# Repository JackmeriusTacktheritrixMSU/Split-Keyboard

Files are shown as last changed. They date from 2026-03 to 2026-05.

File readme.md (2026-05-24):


	This is a split keyboard loosely based on Hack Club's (https://stasis.hackclub.com/starter-projects/split-keyboard.)
It runs from bluetooth, on two NRF52840 Pro Micro clone boards that you can get on aliexpress for cheap. 

Why'd I make it?
Its a bit of a deviation from the standard split keyboard dealy. Generally people use these same switches, but they

A. Expose the MCU on the top face of the keyboard halves
B. Use very few keys (Like a 45 percent keyboard or something along those lines)
and 
C. Use super flat, spread out keycaps.
I'm not crazy about any of these. I like traditional keyboards okay, and I have no idea how people remember which key is which on their splits. I wanted mine to be more standard- with the split for ergnomics but fairly status quo
everywhere else. I like the feeling of regular keycaps-- I like the look as well. I wanted to design my own keycaps. I got the little plug insert bits just from user fivedee on printables \
(https://www.printables.com/model/1069263-15x15-minimal-spaced-kailh-choc-keycap/files)  
Everything else I cut out and built my own. The result is some monster sized caps- turning low profile switches into a very much not low profile keyboard- which is what I wanted, but I might need to change things in the future and 
make my caps lighter. As of now they are untested. 
Capture

The design is screws coming up from the bottom. The two sides mesh together with a nice offset surface.
FinalReal
The PCB is actually reversed for the final- because it has kailh hot swap switches on it


BOM
| Item | Count | Price Per Unit | Total Price | Link | Status |
|---|---:|---:|---:|---|---|
| M2 Heatset Inserts (3.2 x 3.2mm) | 21 | N/A | N/A | N/A | Have |
| NRF52840 Dev Board | Pack x2 | N/A | $0.99 | [Link](https://www.aliexpress.us/item/3256807018711621.html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) | Need |
| PCB | Pack x5 (dev min) | N/A | $25.70 | N/A? | Need |
| Li-ion Poly Battery 5000mAh | Pack x2 | N/A | $14.13 | [Link](https://www.aliexpress.us/item/3256809787664995.html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) | Need |
| Choc V1 Switches | 77 | N/A | N/A | [Link](https://www.aliexpress.us/item/3256809185516557.html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) | Have |
| PG1350 Sockets | 77 | N/A | N/A | [Link](https://www.aliexpress.us/item/3256805079542148.html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) | Have |
| 1N4184W Diodes | 100 | N/A | $4.77 | [Link](https://www.aliexpress.us/item/3256809772352005.html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) | Need |
| 0805 820k Ohm SMD resistor | 100 | N/A | N/A | N/A | Have? |
| 0805 2M Ohm SMD resistor | 100 | N/A | N/A | N/A | Have? |
| M2 Screws (20mm x8 and 4mm x8)| 16 | N/A | N/A | N/A | Have? |
| 3DPrinted Shells+Plate| 3 | N/A | N/A | N/A | Have? |
| Shipping |  |  | $20.73 |  |  |
| Coupons |  |  | -$13.00 |  |  |
| **Total** |  |  | **$53.32** |  |  |

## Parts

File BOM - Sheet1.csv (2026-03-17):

Item | Count | Price Per Unit | Total Price | Link | Status
M2 Heatset Inserts (3.2 x 3.2mm | 21 | N/A | N/A | N/A | Have
NRF52840 Dev Board | Pack x2 | N/A | $0.99 | https://www.aliexpress.us/item/3256807018711621.html?mp=1 | Need
PCB | Pack x5 (dev min) | N/A | $25.70 | N/A? | Need
Li-ion Poly Battery 5000mAh | Pack x2 | N/A | $14.13 | https://www.aliexpress.us/item/3256809787664995.html?mp=1 | Need
Choc V1 Switches | 77 | N/A | N/A | https://www.aliexpress.us/item/3256809185516557.html?src=google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 | Have
PG1350 Sockets | 77 | N/A | N/A | https://www.aliexpress.us/item/3256805079542148.html?src=google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 | Have
1N4184W Diodes | 100 | N/A | $4.77 | https://www.aliexpress.us/item/3256809772352005.html?mp=1 | Need
0805 820k Ohm SMD resistor | 100 | N/A | N/A | N/A | Have?
0805 2M Ohm SMD resistor | 100 | N/A | N/A | N/A | Have?
Shipping |  |  | $20.73
Coupons |  |  | -$13
Total |  |  | $53.32

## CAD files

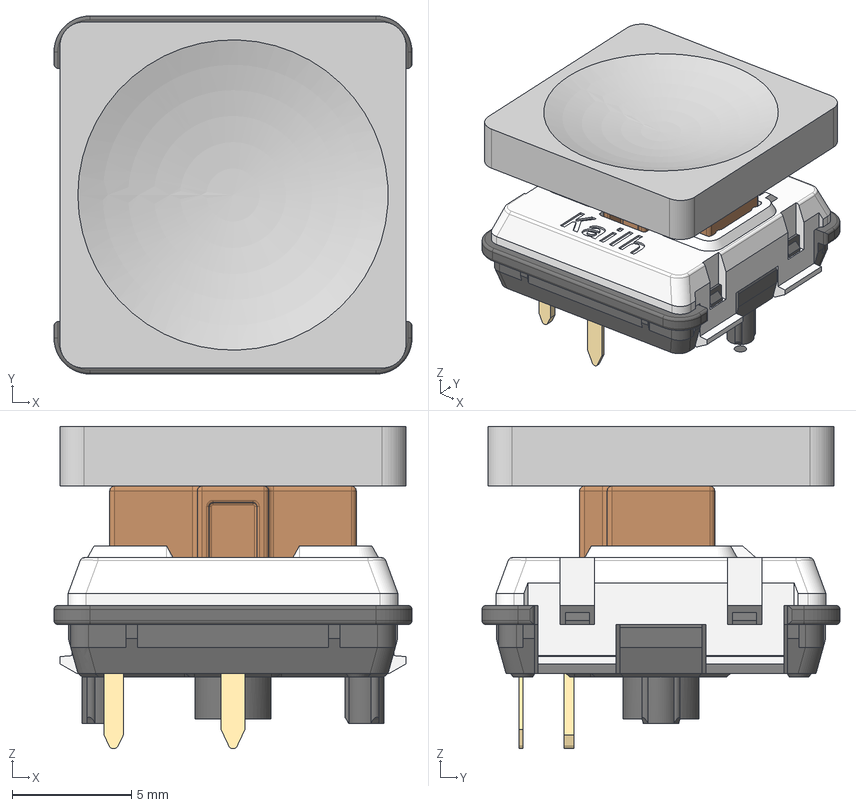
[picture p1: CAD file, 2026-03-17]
CAD Assembly/minspaced-choc-keycap.step
15.0 x 15.0 x 13.5 mm

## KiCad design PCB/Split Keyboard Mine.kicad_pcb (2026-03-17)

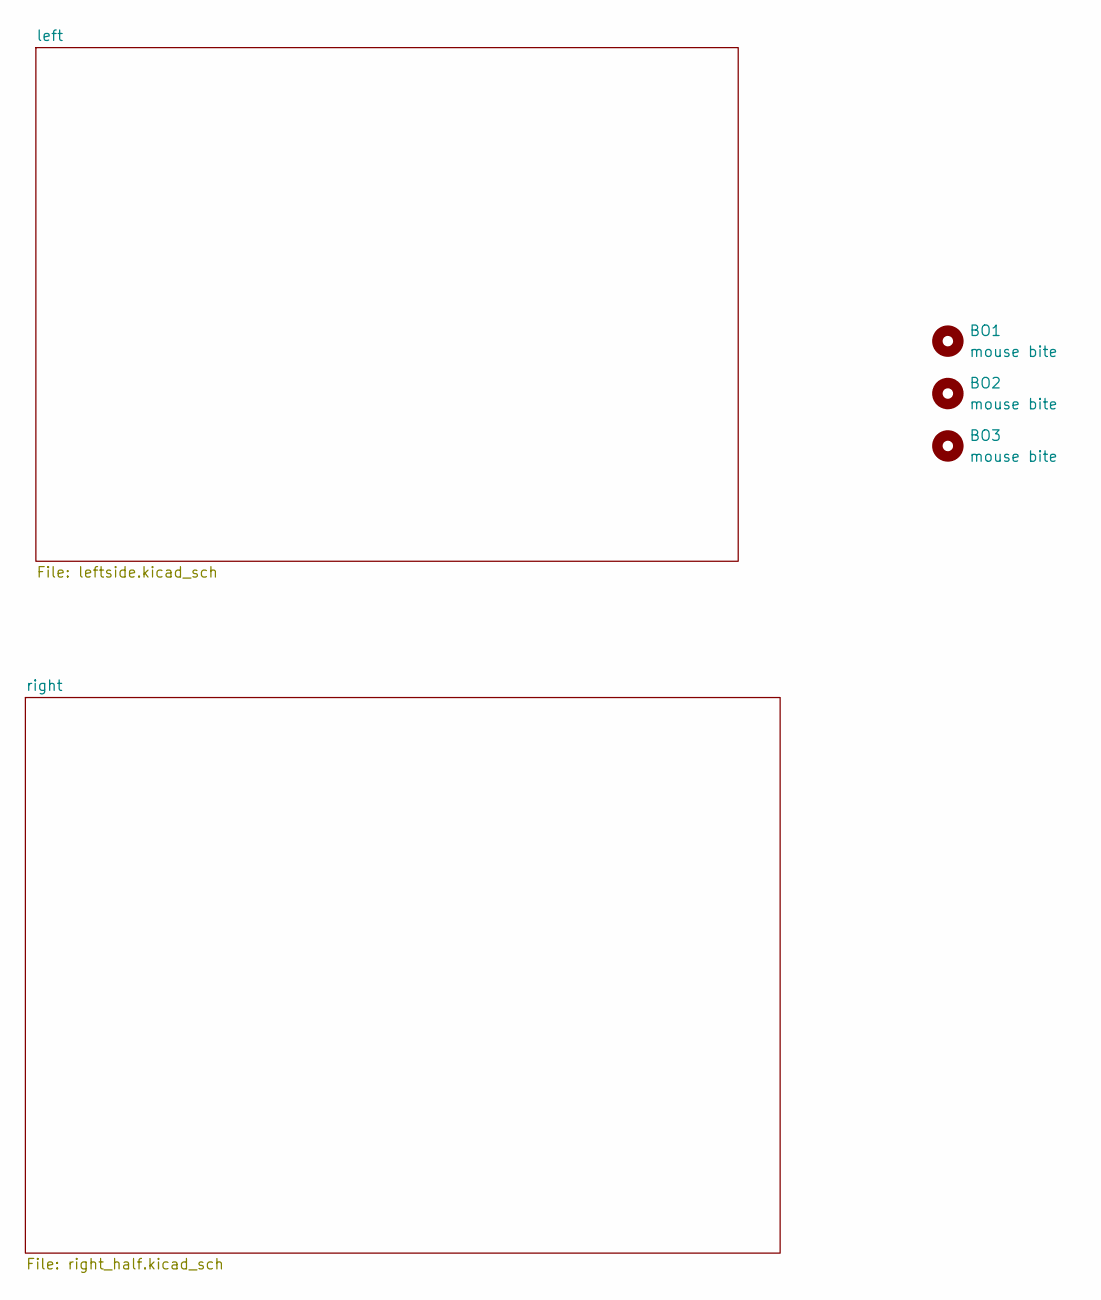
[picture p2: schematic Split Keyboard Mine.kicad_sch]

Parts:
BO1, BO2, BO3: mouse bite; mouse-bite-5mm-slot

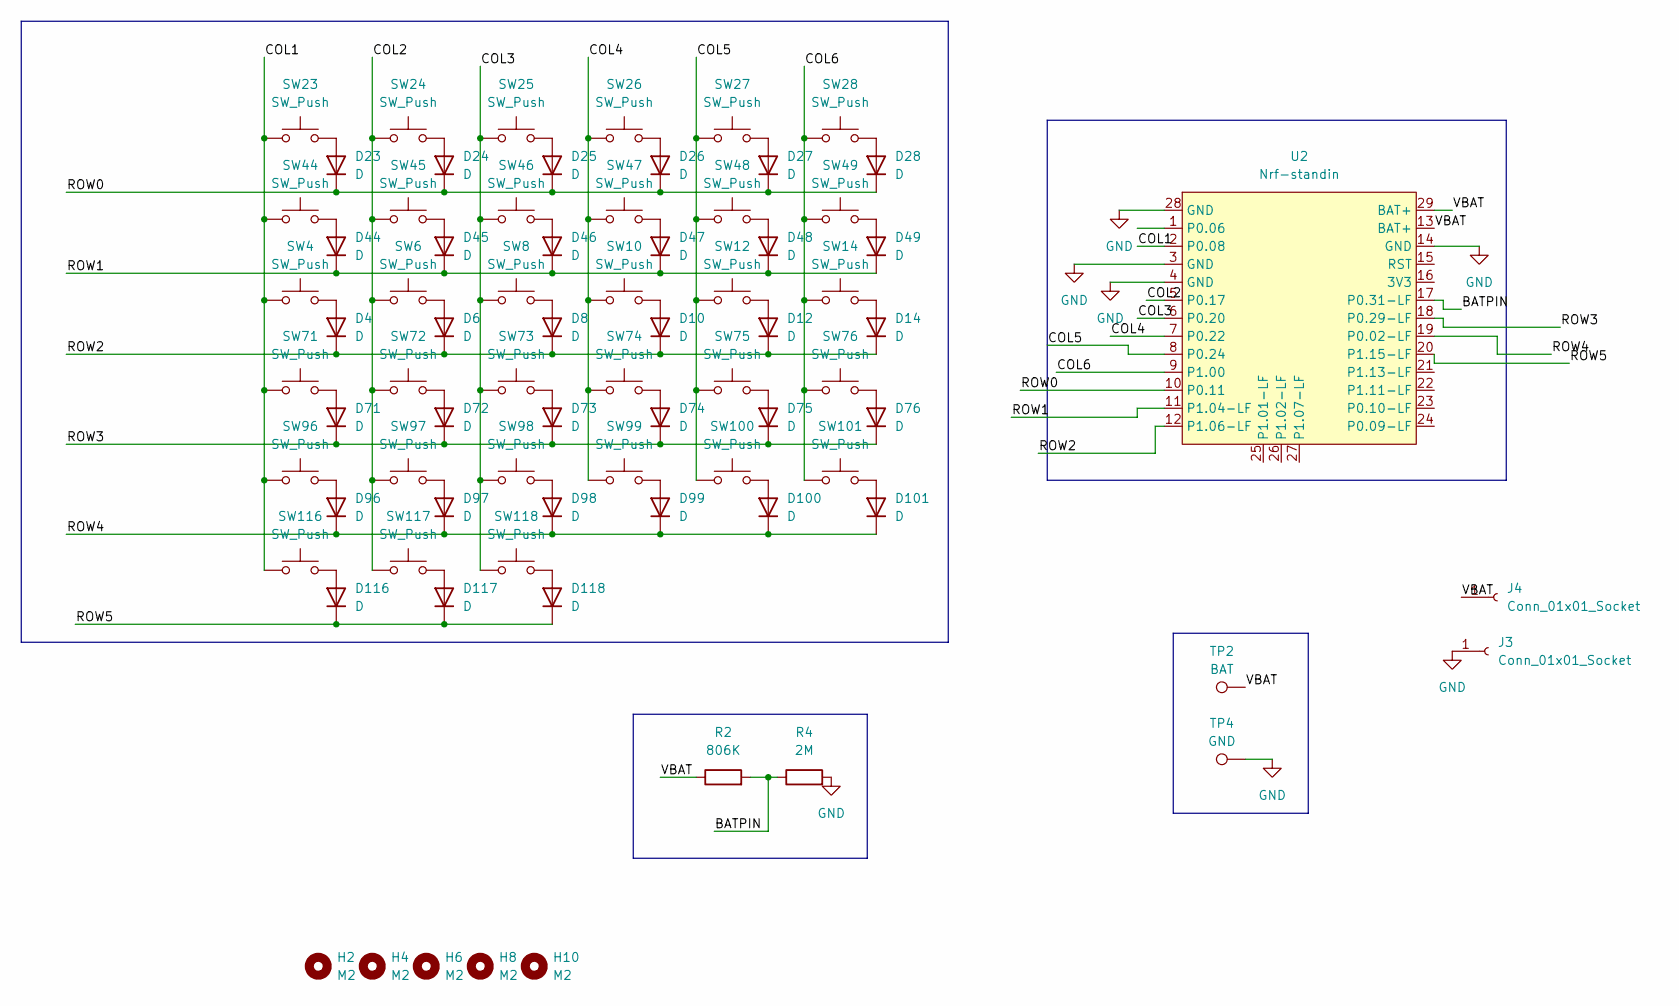
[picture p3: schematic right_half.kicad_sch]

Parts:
D4, D6, D8, D10, D12, D14, D23, D24, D25, D26, D27, D28, D44, D45, D46, D47, D48, D49, D71, D72, D73, D74, D75, D76, D96, D97, D98, D99, D100, D101, D116, D117, D118: D; D_SOD-123
H2, H4, H6, H8, H10: M2; MountingHole_2.2mm_M2
J3, J4: Conn_01x01_Socket; SolderWirePad_1x01_SMD_2x4mm
R2: 806K; R_0805_2012Metric
R4: 2M; R_0805_2012Metric
SW4, SW6, SW8, SW10, SW12, SW23, SW24, SW25, SW26, SW27, SW28, SW44, SW45, SW46, SW47, SW48, SW49, SW71, SW72, SW73, SW74, SW75, SW96, SW97, SW98, SW99, SW100, SW117, SW118: SW_Push; SW_choc_v1_HS_CPG135001S30_1u
SW14: SW_Push; SW_choc_v1_HS_CPG135001S30_1.25u
SW76: SW_Push; SW_choc_v1_HS_CPG135001S30_1.5u
SW101, SW116: SW_Push; SW_choc_v1_HS_CPG135001S30_1.75u
TP2: BAT; TestPoint_Pad_D2.0mm
TP4: GND; TestPoint_Pad_D2.0mm
U2: Nrf-standin; SuperMini_nRF52840_AH_Reversible

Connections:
/right/BATPIN: R2.2, R4.1, U2.17 (P0.31-LF)
/right/COL1: SW4.1, SW23.1, SW44.1, SW71.1, SW96.1, SW116.1, U2.2 (P0.08)
/right/COL2: SW6.1, SW24.1, SW45.1, SW72.1, SW97.1, SW117.1, U2.5 (P0.17)
/right/COL3: SW8.1, SW25.1, SW46.1, SW73.1, SW98.1, SW118.1, U2.6 (P0.20)
/right/COL4: SW10.1, SW26.1, SW47.1, SW74.1, SW99.1, U2.7 (P0.22)
/right/COL5: SW12.1, SW27.1, SW48.1, SW75.1, SW100.1, U2.8 (P0.24)
/right/COL6: SW14.1, SW28.1, SW49.1, SW76.1, SW101.1, U2.9 (P1.00)
/right/ROW0: D23.1 (K), D24.1 (K), D25.1 (K), D26.1 (K), D27.1 (K), D28.1 (K), U2.10 (P0.11)
/right/ROW1: D44.1 (K), D45.1 (K), D46.1 (K), D47.1 (K), D48.1 (K), D49.1 (K), U2.11 (P1.04-LF)
/right/ROW2: D4.1 (K), D6.1 (K), D8.1 (K), D10.1 (K), D12.1 (K), D14.1 (K), U2.12 (P1.06-LF)
/right/ROW3: D71.1 (K), D72.1 (K), D73.1 (K), D74.1 (K), D75.1 (K), D76.1 (K), U2.18 (P0.29-LF)
/right/ROW4: D96.1 (K), D97.1 (K), D98.1 (K), D99.1 (K), D100.1 (K), D101.1 (K), U2.19 (P0.02-LF)
/right/ROW5: D116.1 (K), D117.1 (K), D118.1 (K), U2.20 (P1.15-LF)
/right/VBAT: J4.1, R2.1, TP2.1, U2.13 (BAT+), U2.29 (BAT+)
GND: J3.1, R4.2, TP4.1, U2.3 (GND), U2.4 (GND), U2.14 (GND), U2.28 (GND); also elsewhere on the board
unnamed: D4.2 (A), SW4.2
unnamed: D6.2 (A), SW6.2
unnamed: D8.2 (A), SW8.2
unnamed: D10.2 (A), SW10.2
unnamed: D12.2 (A), SW12.2
unnamed: D14.2 (A), SW14.2
unnamed: D23.2 (A), SW23.2
unnamed: D24.2 (A), SW24.2
unnamed: D25.2 (A), SW25.2
unnamed: D26.2 (A), SW26.2
unnamed: D27.2 (A), SW27.2
unnamed: D28.2 (A), SW28.2
unnamed: D44.2 (A), SW44.2
unnamed: D45.2 (A), SW45.2
unnamed: D46.2 (A), SW46.2
unnamed: D47.2 (A), SW47.2
unnamed: D48.2 (A), SW48.2
unnamed: D49.2 (A), SW49.2
unnamed: D71.2 (A), SW71.2
unnamed: D72.2 (A), SW72.2
unnamed: D73.2 (A), SW73.2
unnamed: D74.2 (A), SW74.2
unnamed: D75.2 (A), SW75.2
unnamed: D76.2 (A), SW76.2
unnamed: D96.2 (A), SW96.2
unnamed: D97.2 (A), SW97.2
unnamed: D98.2 (A), SW98.2
unnamed: D99.2 (A), SW99.2
unnamed: D100.2 (A), SW100.2
unnamed: D101.2 (A), SW101.2
unnamed: D116.2 (A), SW116.2
unnamed: D117.2 (A), SW117.2
unnamed: D118.2 (A), SW118.2

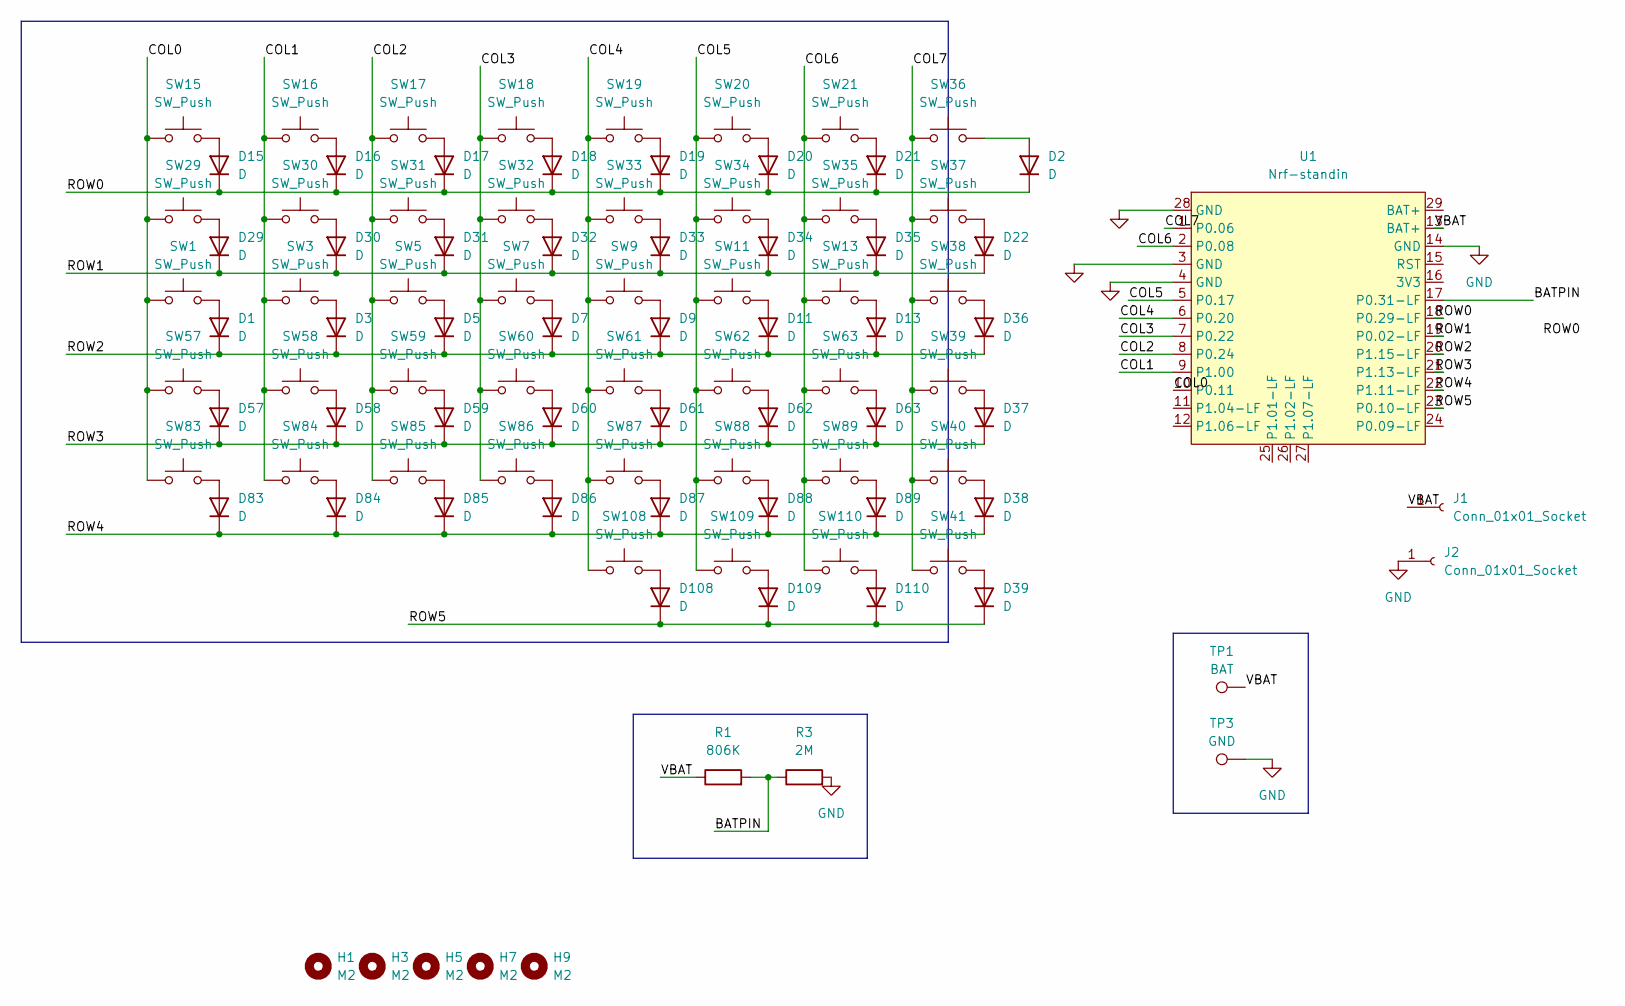
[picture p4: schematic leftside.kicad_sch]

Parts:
D1, D2, D3, D5, D7, D9, D11, D13, D15, D16, D17, D18, D19, D20, D21, D22, D29, D30, D31, D32, D33, D34, D35, D36, D37, D38, D39, D57, D58, D59, D60, D61, D62, D63, D83, D84, D85, D86, D87, D88, D89, D108, D109, D110: D; D_SOD-123
H1, H3, H5, H7, H9: M2; MountingHole_2.2mm_M2
J1, J2: Conn_01x01_Socket; SolderWirePad_1x01_SMD_2x4mm
R1: 806K; R_0805_2012Metric
R3: 2M; R_0805_2012Metric
SW1, SW57: SW_Push; SW_choc_v1_HS_CPG135001S30_1.25u
SW3, SW5, SW7, SW9, SW11, SW13, SW15, SW16, SW17, SW18, SW19, SW20, SW21, SW30, SW31, SW32, SW33, SW34, SW35, SW36, SW37, SW38, SW39, SW40, SW58, SW59, SW60, SW61, SW62, SW63, SW83, SW84, SW85, SW86, SW87, SW88, SW89, SW108, SW109, SW110: SW_Push; SW_choc_v1_HS_CPG135001S30_1u
SW29, SW41: SW_Push; SW_choc_v1_HS_CPG135001S30_1.75u
TP1: BAT; TestPoint_Pad_D2.0mm
TP3: GND; TestPoint_Pad_D2.0mm
U1: Nrf-standin; SuperMini_nRF52840_AH_Reversible

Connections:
/left/BATPIN: R1.2, R3.1, U1.17 (P0.31-LF)
/left/COL0: SW1.1, SW15.1, SW29.1, SW57.1, SW83.1, U1.10 (P0.11)
/left/COL1: SW3.1, SW16.1, SW30.1, SW58.1, SW84.1, U1.9 (P1.00)
/left/COL2: SW5.1, SW17.1, SW31.1, SW59.1, SW85.1, U1.8 (P0.24)
/left/COL3: SW7.1, SW18.1, SW32.1, SW60.1, SW86.1, U1.7 (P0.22)
/left/COL4: SW9.1, SW19.1, SW33.1, SW61.1, SW87.1, SW108.1, U1.6 (P0.20)
/left/COL5: SW11.1, SW20.1, SW34.1, SW62.1, SW88.1, SW109.1, U1.5 (P0.17)
/left/COL6: SW13.1, SW21.1, SW35.1, SW63.1, SW89.1, SW110.1, U1.2 (P0.08)
/left/COL7: SW36.1, SW37.1, SW38.1, SW39.1, SW40.1, SW41.1, U1.1 (P0.06)
/left/ROW0: D2.1 (K), D15.1 (K), D16.1 (K), D17.1 (K), D18.1 (K), D19.1 (K), D20.1 (K), D21.1 (K), U1.18 (P0.29-LF)
/left/ROW1: D22.1 (K), D29.1 (K), D30.1 (K), D31.1 (K), D32.1 (K), D33.1 (K), D34.1 (K), D35.1 (K), U1.19 (P0.02-LF)
/left/ROW2: D1.1 (K), D3.1 (K), D5.1 (K), D7.1 (K), D9.1 (K), D11.1 (K), D13.1 (K), D36.1 (K), U1.20 (P1.15-LF)
/left/ROW3: D37.1 (K), D57.1 (K), D58.1 (K), D59.1 (K), D60.1 (K), D61.1 (K), D62.1 (K), D63.1 (K), U1.21 (P1.13-LF)
/left/ROW4: D38.1 (K), D83.1 (K), D84.1 (K), D85.1 (K), D86.1 (K), D87.1 (K), D88.1 (K), D89.1 (K), U1.22 (P1.11-LF)
/left/ROW5: D39.1 (K), D108.1 (K), D109.1 (K), D110.1 (K), U1.23 (P0.10-LF)
/left/VBAT: J1.1, R1.1, TP1.1, U1.13 (BAT+)
GND: J2.1, R3.2, TP3.1, U1.3 (GND), U1.4 (GND), U1.14 (GND), U1.28 (GND); also elsewhere on the board
unnamed: D1.2 (A), SW1.2
unnamed: D2.2 (A), SW36.2
unnamed: D3.2 (A), SW3.2
unnamed: D5.2 (A), SW5.2
unnamed: D7.2 (A), SW7.2
unnamed: D9.2 (A), SW9.2
unnamed: D11.2 (A), SW11.2
unnamed: D13.2 (A), SW13.2
unnamed: D15.2 (A), SW15.2
unnamed: D16.2 (A), SW16.2
unnamed: D17.2 (A), SW17.2
unnamed: D18.2 (A), SW18.2
unnamed: D19.2 (A), SW19.2
unnamed: D20.2 (A), SW20.2
unnamed: D21.2 (A), SW21.2
unnamed: D22.2 (A), SW37.2
unnamed: D29.2 (A), SW29.2
unnamed: D30.2 (A), SW30.2
unnamed: D31.2 (A), SW31.2
unnamed: D32.2 (A), SW32.2
unnamed: D33.2 (A), SW33.2
unnamed: D34.2 (A), SW34.2
unnamed: D35.2 (A), SW35.2
unnamed: D36.2 (A), SW38.2
unnamed: D37.2 (A), SW39.2
unnamed: D38.2 (A), SW40.2
unnamed: D39.2 (A), SW41.2
unnamed: D57.2 (A), SW57.2
unnamed: D58.2 (A), SW58.2
unnamed: D59.2 (A), SW59.2
unnamed: D60.2 (A), SW60.2
unnamed: D61.2 (A), SW61.2
unnamed: D62.2 (A), SW62.2
unnamed: D63.2 (A), SW63.2
unnamed: D83.2 (A), SW83.2
unnamed: D84.2 (A), SW84.2
unnamed: D85.2 (A), SW85.2
unnamed: D86.2 (A), SW86.2
unnamed: D87.2 (A), SW87.2
unnamed: D88.2 (A), SW88.2
unnamed: D89.2 (A), SW89.2
unnamed: D108.2 (A), SW108.2
unnamed: D109.2 (A), SW109.2
unnamed: D110.2 (A), SW110.2

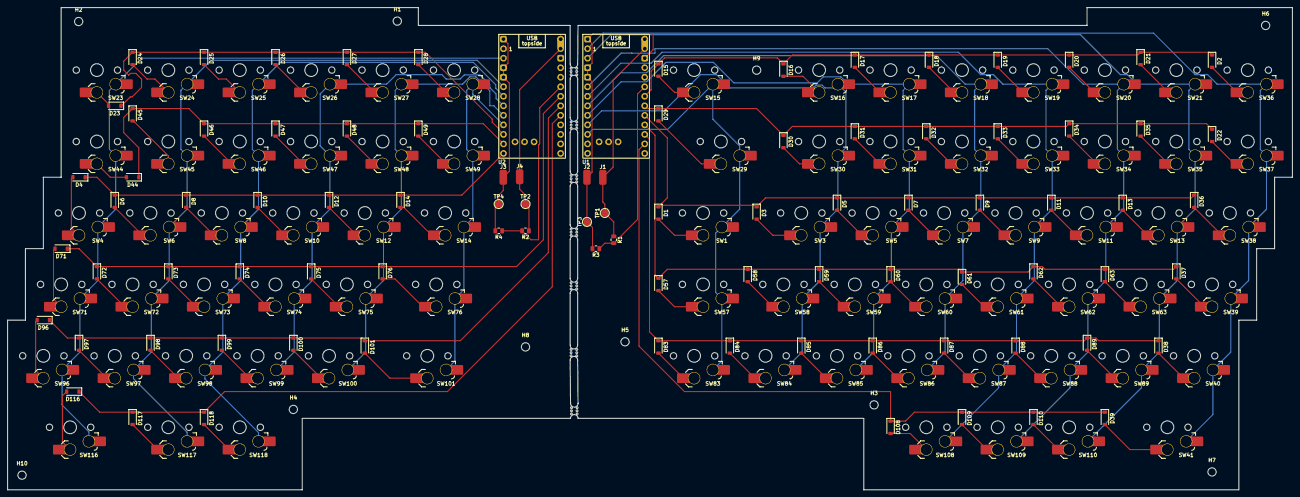
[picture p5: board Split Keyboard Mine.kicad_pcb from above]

Board: 2 copper layers, 342.6 x 128.6 mm, 178 parts (0 on the bottom side), 108 nets.
